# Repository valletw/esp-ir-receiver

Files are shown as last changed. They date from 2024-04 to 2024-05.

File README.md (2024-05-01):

# ESP32 Infra-Red Receiver

This project is made to receive IR transmitter information (TV remote) and
control something over WiFi. This project will be used for
[UPnP remote controller project](https://github.com/valletw/esp-upnp-remote).

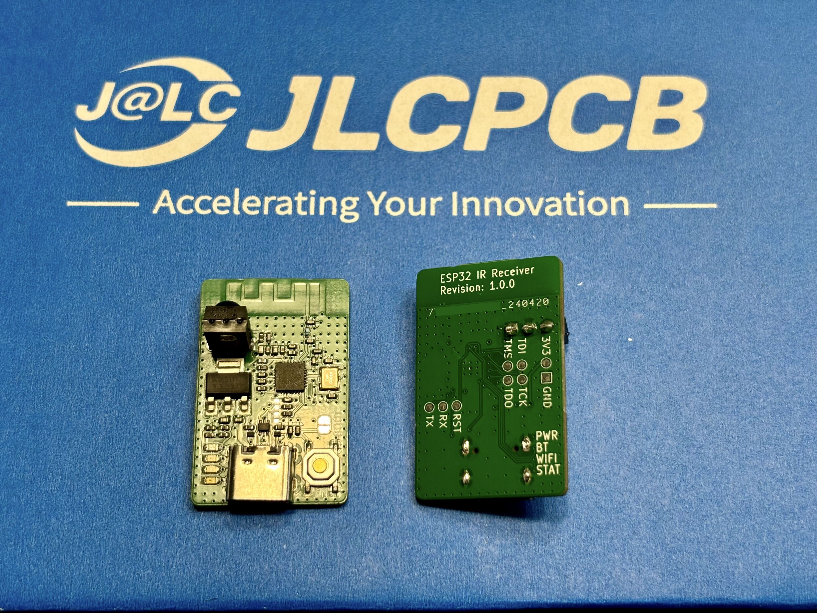
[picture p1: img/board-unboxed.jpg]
Board


## Hardware

Four status LED are available:

- `PWR`: 3.3V state
- `BT`: Bluetooth / BLE pairing status
- `WIFI`: WiFi connection status
- `STAT`: Software protocol status

Two buttons are available:

- `BOOT`: Control processor download mode on boot
- `EN`: Control processor reset

For advanced debug, test points are available for JTAG probe and UART controller.

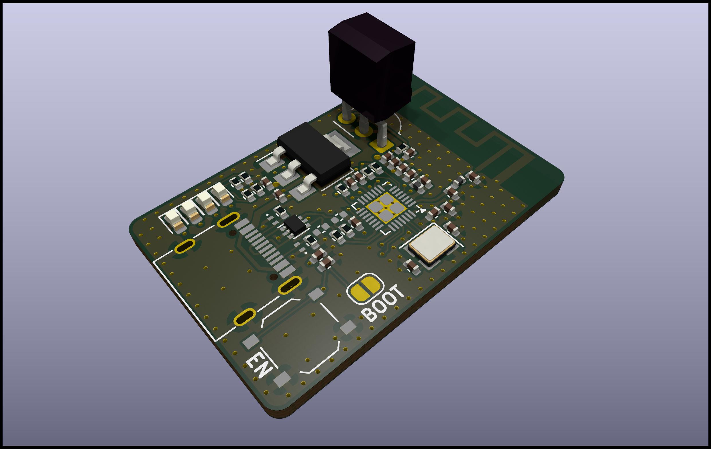
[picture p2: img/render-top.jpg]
Board top render

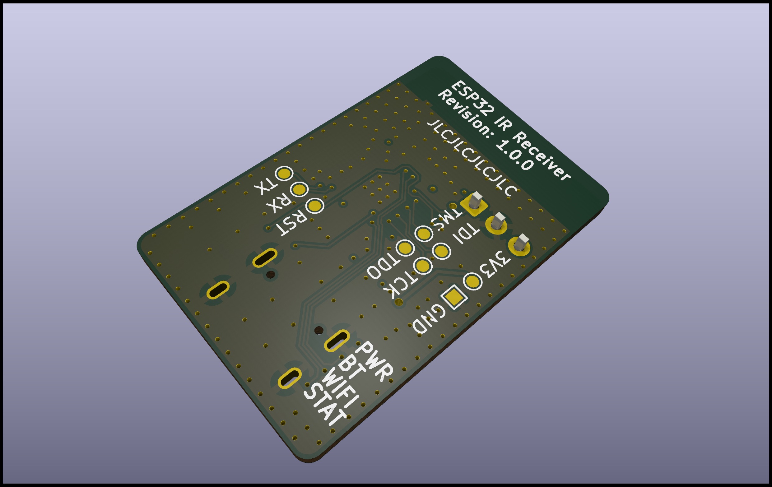
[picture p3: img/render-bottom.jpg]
Board bottom render


*Note: 3D shapes were not fully configured on my setup, so some components are not
displayed in the render, to be fix.*

### Components choice

This project is based on an ESP32-C3 SoC: `ESP8685H4` (4 MB Flash with no
PSRAM). ESP32 has been selected for the WiFi & Bluetooth support and the big
community to generate easily a software. The choice of "C3" is to ensure support
with the SDK for longer time and minimal footprint. ESP32 modules have not been
kept due to PCB assembly fees. Espressif hardware design rules has been take into
account following there
[documentation](https://docs.espressif.com/projects/esp-hardware-design-guidelines/en/latest/esp32c3/pcb-layout-design.html)

USB-UART bridge has not been added to reduce the number of component. The ESP32
support direct USB connection to manage debug mode with firmware download, and
UART communication.

The 3.3V to power all the components is generated from an LDO using the 5V of the
USB socket.

All others components has been selected from [JLCPCB](https://jlcpcb.com/parts/)
catalogue to minimize the cost and the assembly fees.

### Manufacturing

The board is manufactured by [JLCPCB](https://jlcpcb.com), here is the details
you will require to generate an order.

*Note: JLCPCB requests some modifications on output files, do not use direct
export from KiCad (check the FAQ)*

#### PCB

Files: [Gerbers](jlcpcb/gerbers.zip)

Configuration              | Value
---------------------------|---------------------------------
Base Materiel              | FR-4
Layers                     | 4
Dimensions                 | 33.14 x 21.45
Different design           | 1
Delivery format            | Single PCB
PCB thickness              | 1.6
PCB color                  | Green (other colors have fees)
Silkscreen                 | White
Materiel type              | FR4-Standard TG 135-140
Surface finish             | HASL
Specify layer sequence     | F_Cu / In1_Cu / In2_Cu / B_Cu
Impedance control          | Yes
Layer stack-up             | JLC04161H-7628
Via covering               | Tented or Plugged
Min via hole size/diameter | 0.3mm/0.4mm
Remove order number        | Specify a location

*Note: All options have not been detail here, keep default value.*

#### Assembly

Files: [BOM](jlcpcb/bom.csv), [CPL](jlcpcb/cpl.csv)

Configuration       | Value
--------------------|--------------------
PCBA type           | Economic
Assembly side       | Top
Tooling holes       | Added by JLCPCB

Verify "pick & place" orientations and positions on the web viewer

JLCPCB will add 2 tooling holes for assembly (1 mm diameter near the board corners).

*Note: All options have not been detail here, keep default value.*

### ESP32 Pinout

For those who want to reuse this project, here is the ESP32 pinout to manage the
different input/output.

Name              | Pin  | Direction
------------------|------|----------
IR Rx             | IO3  | Input
WiFi status       | IO0  | Output
Bluetooth status  | IO1  | Output
Software status   | IO10 | Output

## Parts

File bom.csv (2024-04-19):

Reference | Qty | Value | Footprint | JLCPCB Part# | Manufacturer | MFR Part#
C101,C103,C117 | 3 | 10u | Capacitor_SMD:C_0402_1005Metric | C15525 | Samsung Electro-Mechanics | CL05A106MQ5NUNC
C102,C104,C105,C108,C109,C116,C118,C119 | 8 | 100n | Capacitor_SMD:C_0402_1005Metric | C1525 | Samsung Electro-Mechanics | CL05B104KO5NNNC
C106 | 1 | 10n | Capacitor_SMD:C_0402_1005Metric | C15195 | Samsung Electro-Mechanics | CL05B103KB5NNNC
C107,C110,C111 | 3 | 1u | Capacitor_SMD:C_0402_1005Metric | C52923 | Samsung Electro-Mechanics | CL05A105KA5NQNC
C112,C113 | 2 | 12p | Capacitor_SMD:C_0402_1005Metric | C1547 | FH (Guangdong Fenghua Advanced Tech) | 0402CG120J500NT
C114,C115 | 2 | 1.8p | Capacitor_SMD:C_0402_1005Metric | C1553 | FH (Guangdong Fenghua Advanced Tech) | 0402CG1R8C500NT
D101 | 1 | Red | LED_SMD:LED_0603_1608Metric | C2286 | Hubei KENTO Elec | KT-0603R
D102,D103,D104 | 3 | Green | LED_SMD:LED_0603_1608Metric | C72043 | Everlight Elec | 19-217/GHC-YR1S2/3T
D105,D106 | 2 | TPD1E05U06 | Package_SON:Texas_DPY0002A_0.6x1mm_P0.65mm | C436349 | Texas Instruments | TPD1E05U06DPYR
J101 | 1 | GT-USB-7010ASV | Connector_USB:USB_C_Receptacle_G-Switch_GT-USB-7010ASV | C2988369 | G-Switch | GT-USB-7010ASV
L101 | 1 | 2n | Inductor_SMD:L_0402_1005Metric | C18216 | Murata Electronics | LQG15HS2N0S02D
L102 | 1 | 2.5n | Inductor_SMD:L_0402_1005Metric | C237342 | Murata Electronics | LQW15AN2N5B00D
R101,R105 | 2 | 200 | Resistor_SMD:R_0402_1005Metric | C25087 | UNI-ROYAL(Uniroyal Elec) | 0402WGF2000TCE
R102,R103,R104 | 3 | 22 | Resistor_SMD:R_0402_1005Metric | C25092 | UNI-ROYAL(Uniroyal Elec) | 0402WGF220JTCE
R106,R107,R108 | 3 | 10k | Resistor_SMD:R_0402_1005Metric | C25744 | UNI-ROYAL(Uniroyal Elec) | 0402WGF1002TCE
R109,R110 | 2 | 5.1k | Resistor_SMD:R_0402_1005Metric | C25905 | UNI-ROYAL(Uniroyal Elec) | 0402WGF5101TCE
R111,R112 | 2 | 0 | Resistor_SMD:R_0402_1005Metric | C17168 | UNI-ROYAL(Uniroyal Elec) | 0402WGF0000TCE
SW101 | 1 | TS-1187A-B-A-B | Button_Switch_SMD:SW_Push_1P1T_XKB_TS-1187A | C318884 | XKB Connectivity | TS-1187A-B-A-B
U101 | 1 | TSOP348xx | OptoDevice:Vishay_MOLD-3Pin | C44620 | Vishay Intertech | TSOP34838
U103 | 1 | USBLC6-2P6 | Package_TO_SOT_SMD:SOT-666 | C15999 | STMicroelectronics | USBLC6-2P6
U104 | 1 | AMS1117-3.3 | Package_TO_SOT_SMD:SOT-223 | C6186 | Advanced Monolithic Systems | AMS1117-3.3
U105 | 1 | ESP8685 | Package_DFN_QFN:QFN-28-1EP_4x4mm_P0.4mm_EP2.6x2.6mm | C4944062 | Espressif | ESP8685H4
Y101 | 1 | 40MHz | Crystal:Crystal_SMD_3225-4Pin_3.2x2.5mm | C2875582 | KYX | K3A4000010.510

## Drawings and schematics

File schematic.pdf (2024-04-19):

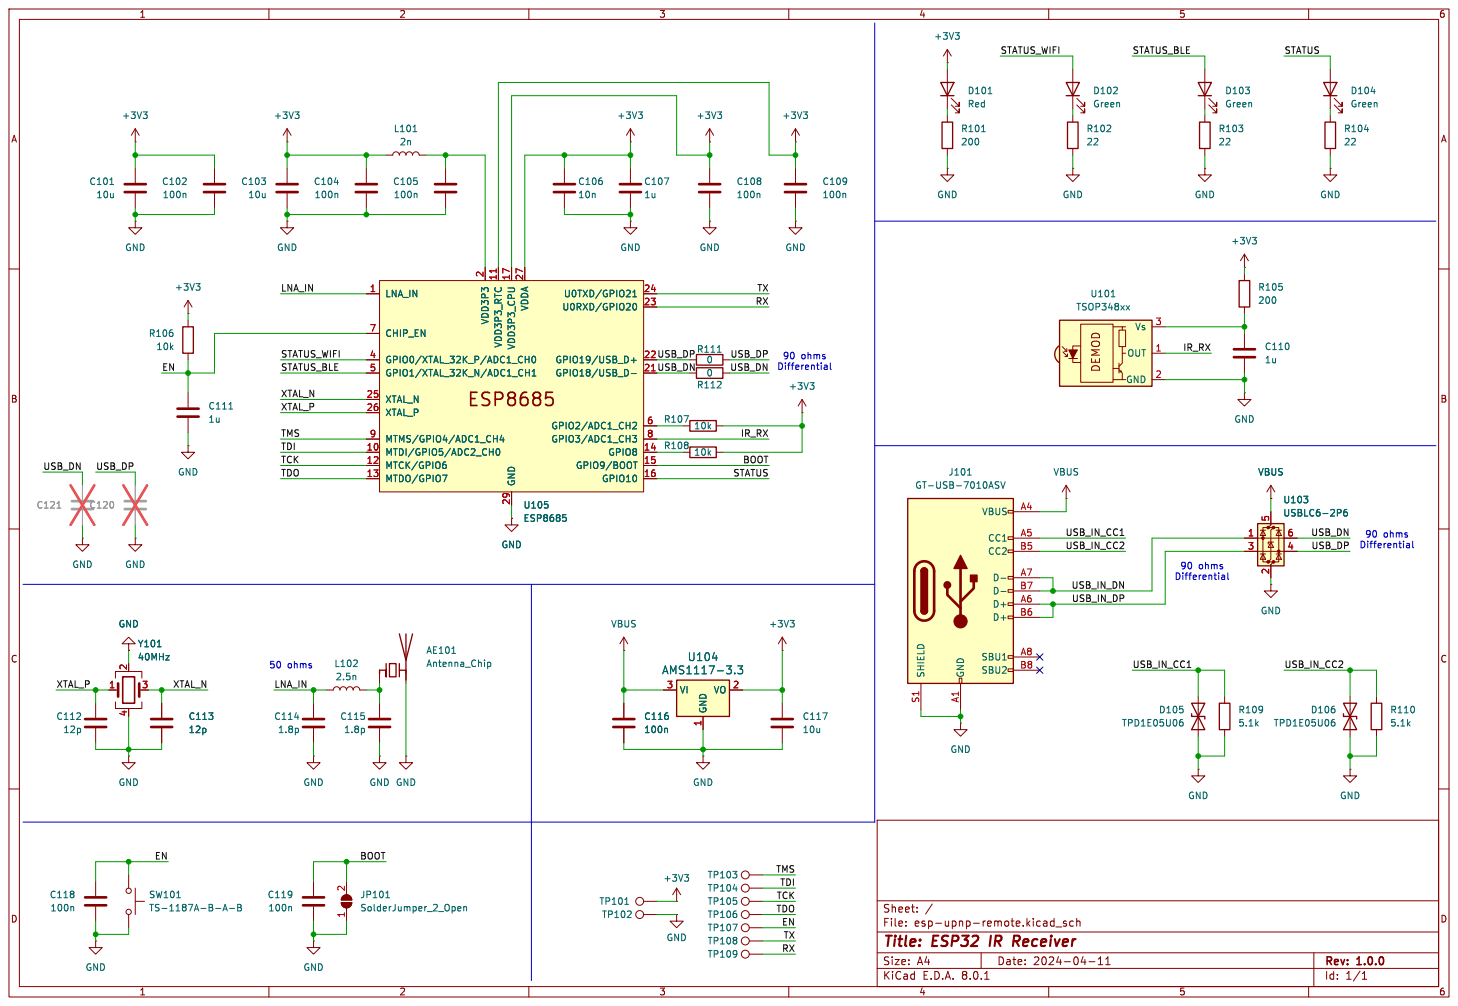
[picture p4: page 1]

Id: 1/1 Title: ESP32 IR Receiver File: esp-upnp-remote.kicad_sch Sheet: /

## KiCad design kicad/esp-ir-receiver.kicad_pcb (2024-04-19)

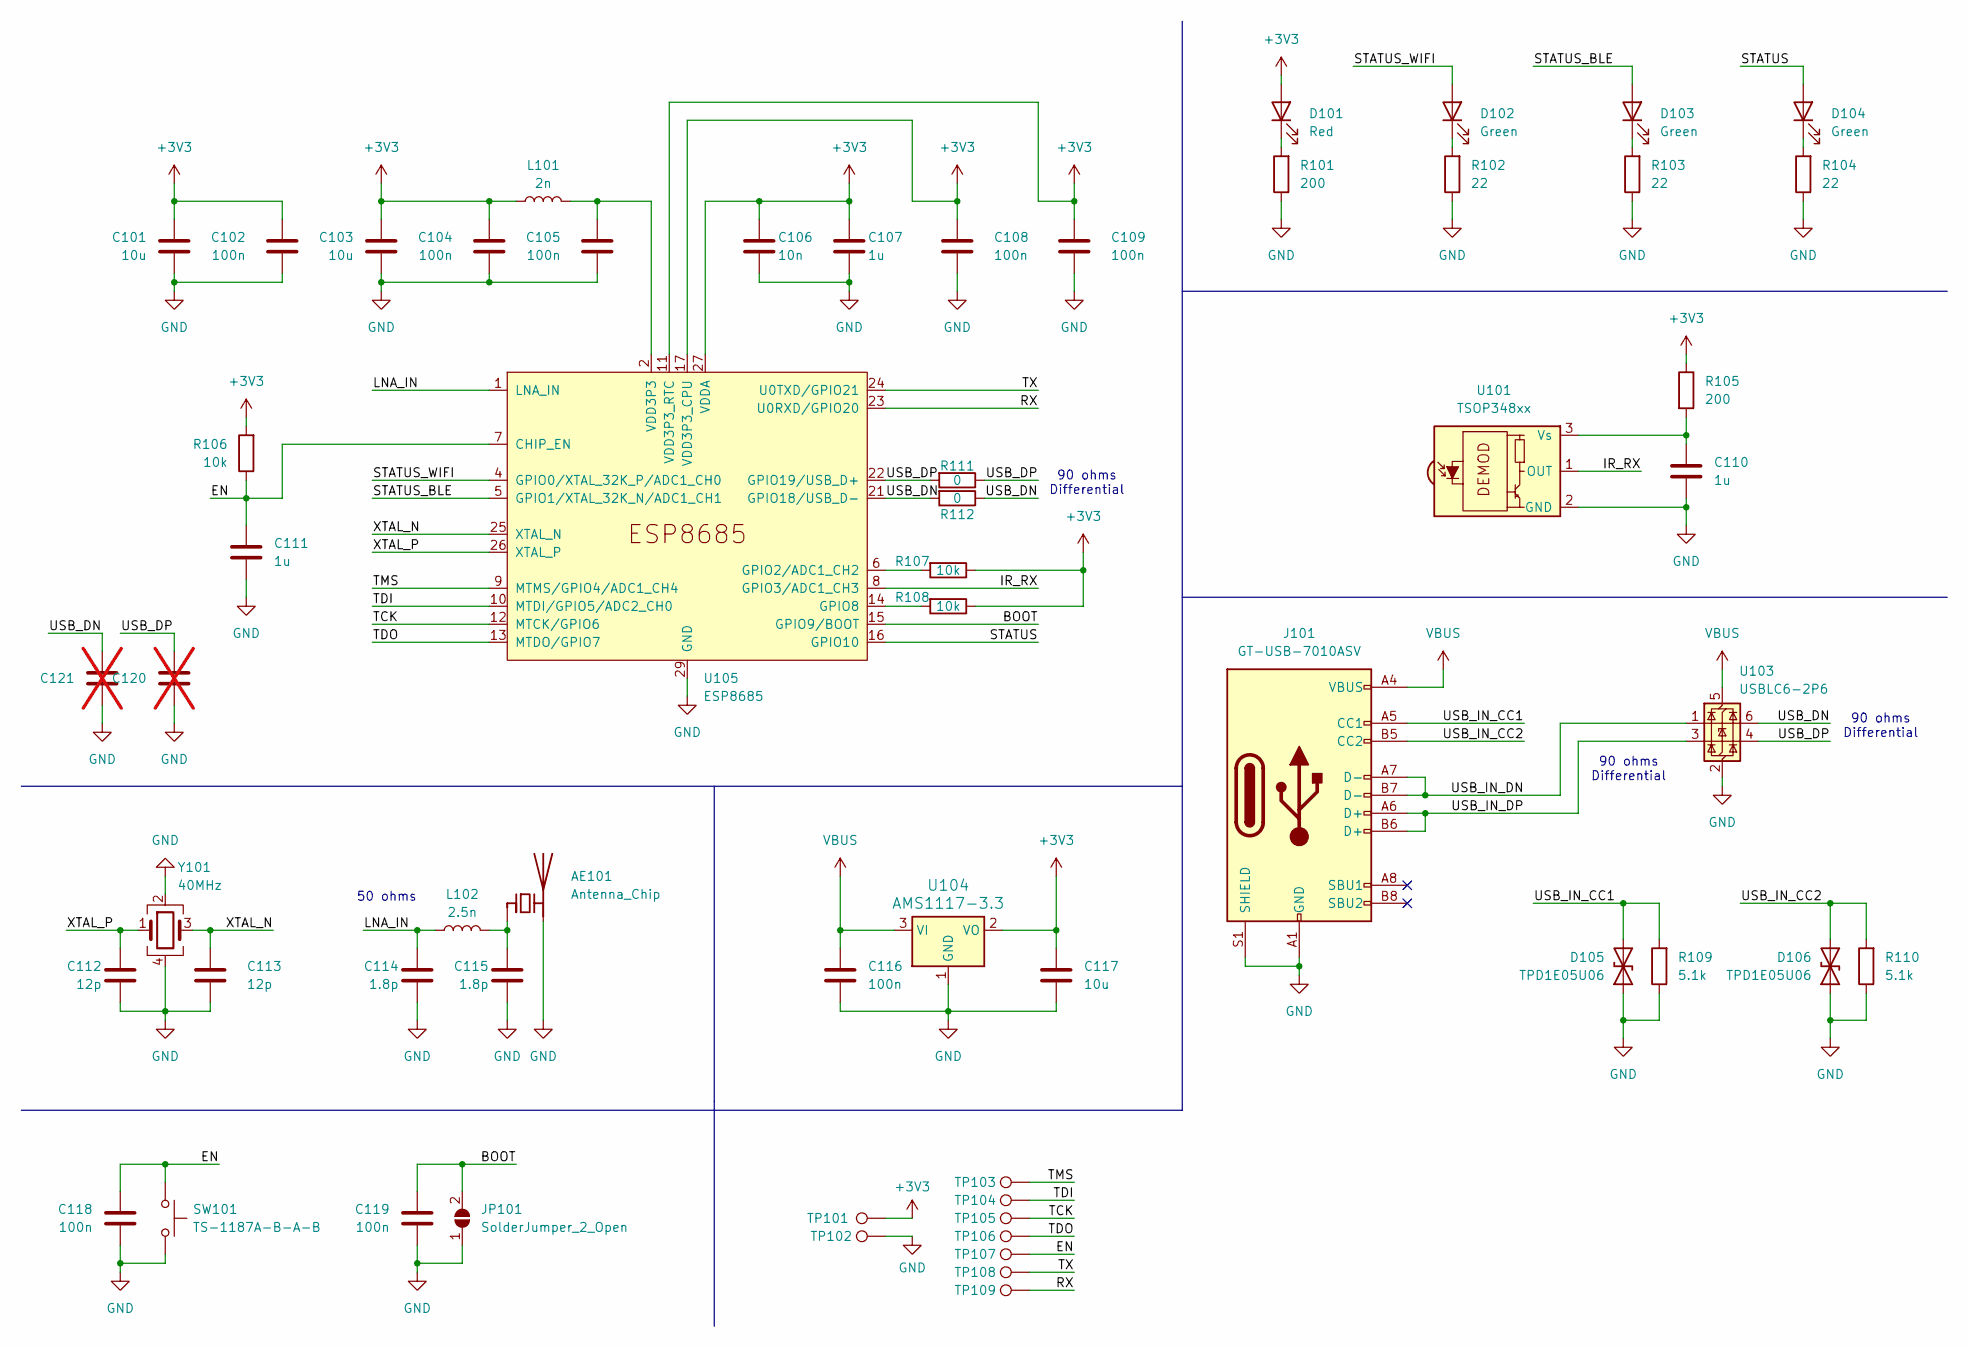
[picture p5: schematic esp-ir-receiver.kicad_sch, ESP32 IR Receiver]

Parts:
AE101: Antenna_Chip; Texas_SWRA117D_2.4GHz_Left
C101, C103, C117: 10u; C_0402_1005Metric; MFR Part# CL05A106MQ5NUNC; JLCPCB Part# C15525
C102, C104, C105, C108, C109, C116, C118, C119: 100n; C_0402_1005Metric; MFR Part# CL05B104KO5NNNC; JLCPCB Part# C1525
C106: 10n; C_0402_1005Metric; MFR Part# CL05B103KB5NNNC; JLCPCB Part# C15195
C107, C110, C111: 1u; C_0402_1005Metric; MFR Part# CL05A105KA5NQNC; JLCPCB Part# C52923
C112, C113: 12p; C_0402_1005Metric; MFR Part# 0402CG120J500NT; JLCPCB Part# C1547
C114, C115: 1.8p; C_0402_1005Metric; MFR Part# 0402CG1R8C500NT; JLCPCB Part# C1553
C120, C121: C_0402_1005Metric; not fitted
D101: Red; LED_0603_1608Metric; MFR Part# KT-0603R; JLCPCB Part# C2286
D102, D103, D104: Green; LED_0603_1608Metric; MFR Part# 19-217/GHC-YR1S2/3T; JLCPCB Part# C72043
D105, D106: TPD1E05U06; Texas_DPY0002A_0.6x1mm_P0.65mm; MFR Part# TPD1E05U06DPYR; JLCPCB Part# C436349
J101: GT-USB-7010ASV; USB_C_Receptacle_G-Switch_GT-USB-7010ASV; MFR Part# GT-USB-7010ASV; JLCPCB Part# C2988369
JP101: SolderJumper_2_Open; SolderJumper-2_P1.3mm_Open_RoundedPad1.0x1.5mm
L101: 2n; L_0402_1005Metric; MFR Part# LQG15HS2N0S02D; JLCPCB Part# C18216
L102: 2.5n; L_0402_1005Metric; MFR Part# LQW15AN2N5B00D; JLCPCB Part# C237342
R101, R105: 200; R_0402_1005Metric; MFR Part# 0402WGF2000TCE; JLCPCB Part# C25087
R102, R103, R104: 22; R_0402_1005Metric; MFR Part# 0402WGF220JTCE; JLCPCB Part# C25092
R106, R107, R108: 10k; R_0402_1005Metric; MFR Part# 0402WGF1002TCE; JLCPCB Part# C25744
R109, R110: 5.1k; R_0402_1005Metric; MFR Part# 0402WGF5101TCE; JLCPCB Part# C25905
R111, R112: 0; R_0402_1005Metric; MFR Part# 0402WGF0000TCE; JLCPCB Part# C17168
SW101: TS-1187A-B-A-B; SW_Push_1P1T_XKB_TS-1187A; MFR Part# TS-1187A-B-A-B; JLCPCB Part# C318884
TP101: 3V3; TestPoint_Pad_D1.0mm
TP102: GND; TestPoint_Pad_1.0x1.0mm
TP103: TMS; TestPoint_Pad_D1.0mm
TP104: TDI; TestPoint_Pad_D1.0mm
TP105: TCK; TestPoint_Pad_D1.0mm
TP106: TDO; TestPoint_Pad_D1.0mm
TP107: RST; TestPoint_Pad_D1.0mm
TP108: TX; TestPoint_Pad_D1.0mm
TP109: RX; TestPoint_Pad_D1.0mm
U101: TSOP348xx; Vishay_MOLD-3Pin; MFR Part# TSOP34838; JLCPCB Part# C44620
U103: USBLC6-2P6; SOT-666; MFR Part# USBLC6-2P6; JLCPCB Part# C15999
U104: AMS1117-3.3; SOT-223; MFR Part# AMS1117-3.3; JLCPCB Part# C6186
U105: ESP8685; QFN-28-1EP_4x4mm_P0.4mm_EP2.6x2.6mm; MFR Part# ESP8685H4; JLCPCB Part# C4944062
Y101: 40MHz; Crystal_SMD_3225-4Pin_3.2x2.5mm; MFR Part# K3A4000010.510; JLCPCB Part# C2875582

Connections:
+3V3: C101.1, C102.2, C103.1, C104.2, C106.2, C107.2, C108.2, C109.2, C117.1, D101.2 (A), L101.2, R105.1, R106.2, R107.1, R108.1, TP101.1, U104.2 (VO), U105.11 (VDD3P3_RTC), U105.17 (VDD3P3_CPU), U105.27 (VDDA), U105.28 (VDDA)
/BOOT: C119.1, JP101.2 (B), U105.15 (GPIO9/BOOT)
/EN: C111.2, C118.1, R106.1, SW101.1, TP107.1, U105.7 (CHIP_EN)
/IR_RX: U101.1 (OUT), U105.8 (GPIO3/ADC1_CH3)
/LNA_IN: C114.1, L102.1, U105.1 (LNA_IN)
/RX: TP109.1, U105.23 (U0RXD/GPIO20)
/STATUS: D104.2 (A), U105.16 (GPIO10)
/STATUS_BLE: D103.2 (A), U105.5 (GPIO1/XTAL_32K_N/ADC1_CH1)
/STATUS_WIFI: D102.2 (A), U105.4 (GPIO0/XTAL_32K_P/ADC1_CH0)
/TCK: TP105.1, U105.12 (MTCK/GPIO6)
/TDI: TP104.1, U105.10 (MTDI/GPIO5/ADC2_CH0)
/TDO: TP106.1, U105.13 (MTDO/GPIO7)
/TMS: TP103.1, U105.9 (MTMS/GPIO4/ADC1_CH4)
/TX: TP108.1, U105.24 (U0TXD/GPIO21)
/USB_DN: C121.2, R112.1, R112.2, U103.6 (I/O1), U105.21 (GPIO18/USB_D-)
/USB_DP: C120.2, R111.1, R111.2, U103.4 (I/O2), U105.22 (GPIO19/USB_D+)
/USB_IN_CC1: D105.2 (A2), J101.A5 (CC1), R109.2
/USB_IN_CC2: D106.2 (A2), J101.B5 (CC2), R110.2
/USB_IN_DN: J101.A7 (D-), J101.B7 (D-), U103.1 (I/O1)
/USB_IN_DP: J101.A6 (D+), J101.B6 (D+), U103.3 (I/O2)
/XTAL_N: C113.1, U105.25 (XTAL_N), Y101.3
/XTAL_P: C112.1, U105.26 (XTAL_P), Y101.1
GND: AE101.2 (PCB_Trace), C101.2, C102.1, C103.2, C104.1, C105.1, C106.1, C107.1, C108.1, C109.1, C110.1, C111.1, C112.2, C113.2, C114.2, C115.2, C116.2, C117.2, C118.2, C119.2, C120.1, C121.1, D105.1 (A1), D106.1 (A1), J101.A1 (GND), J101.A12 (GND), J101.B1 (GND), J101.B12 (GND), J101.S1 (SHIELD), JP101.1 (A), R101.1, R102.1, R103.1, R104.1, R109.1, R110.1, SW101.2, TP102.1, U101.2 (GND), U103.2 (GND), U104.1 (GND), U105.29 (GND), Y101.2, Y101.4
unnamed: AE101.1 (FEED), C115.1, L102.2
unnamed: C105.2, L101.1, U105.2 (VDD3P3), U105.3 (VDD3P3)
unnamed: D101.1 (K), R101.2
unnamed: D102.1 (K), R102.2
unnamed: D103.1 (K), R103.2
unnamed: D104.1 (K), R104.2
unnamed: C110.2, R105.2, U101.3 (Vs)
unnamed: R107.2, U105.6 (GPIO2/ADC1_CH2)
unnamed: R108.2, U105.14 (GPIO8)
VBUS: C116.1, J101.A4 (VBUS), J101.A9 (VBUS), J101.B4 (VBUS), J101.B9 (VBUS), U103.5 (VBUS), U104.3 (VI)

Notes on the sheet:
50 ohms
90 ohms Differential

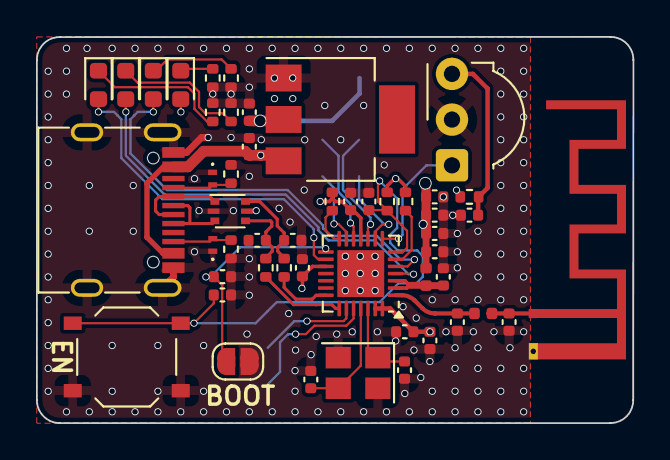
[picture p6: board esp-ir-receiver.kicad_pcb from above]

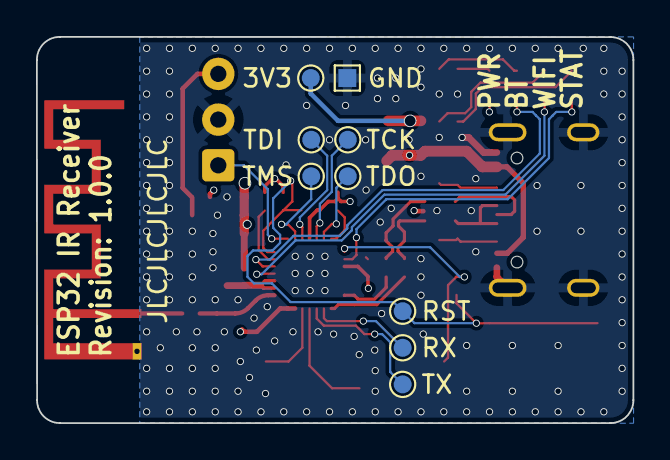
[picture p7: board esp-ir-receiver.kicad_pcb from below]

Board: 4 copper layers, 33.1 x 21.5 mm, 59 parts (9 on the bottom side), 33 nets.

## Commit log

2024-04-19 Provide KiCad project files
    [esp-ir-receiver.kicad_pcb, esp-ir-receiver.kicad_sch]
2024-04-19 Provide manufacturing files
    [bom.csv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]

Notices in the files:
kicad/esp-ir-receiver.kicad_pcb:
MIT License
